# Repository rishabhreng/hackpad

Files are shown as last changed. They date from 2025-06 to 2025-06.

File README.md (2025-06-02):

# MacroPad Overview

A 6-key macropad, in an "A" shape, with a 0.91" OLED display and a rotary encoder. It also has one LED under the central key, and everything is controlled with KMK firmware.

This was my first time designing a macropad or any other  electronics with KiCad, and I really enjoyed it (esp. learning more about the wiring). Fortunately, I have some experience with CAD in Onshape, so modeling the case went smoothly.

| | |
|---|---|
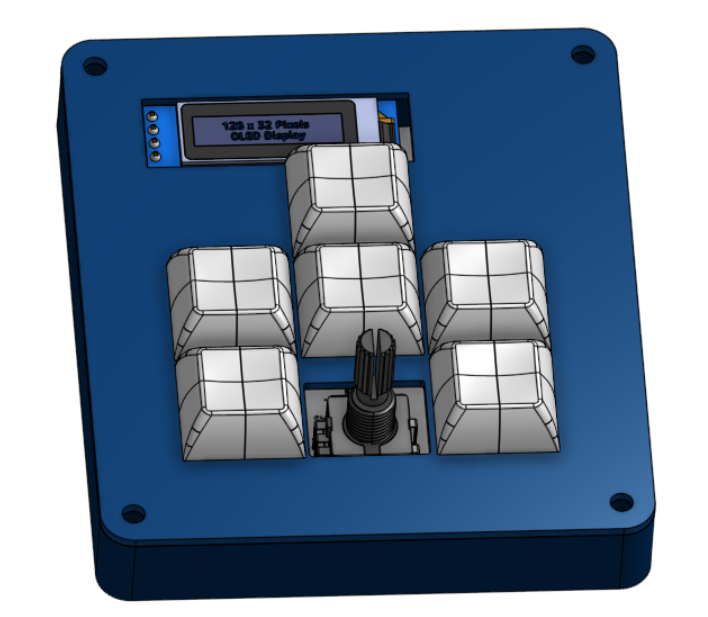
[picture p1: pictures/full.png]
3D model of my macropad
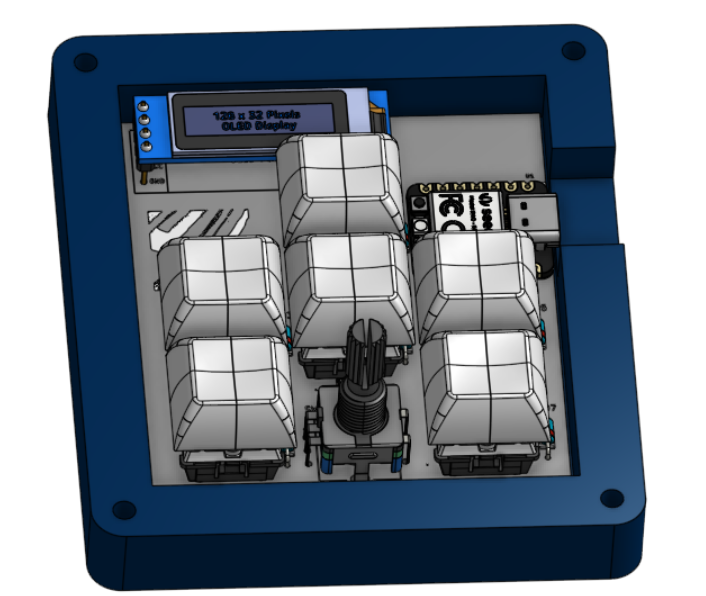
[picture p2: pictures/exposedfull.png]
full macropad, exposed PCB
|  |  |

## Pictures

| Schematic | PCB | Case |
|:-:|:-:|:-:|
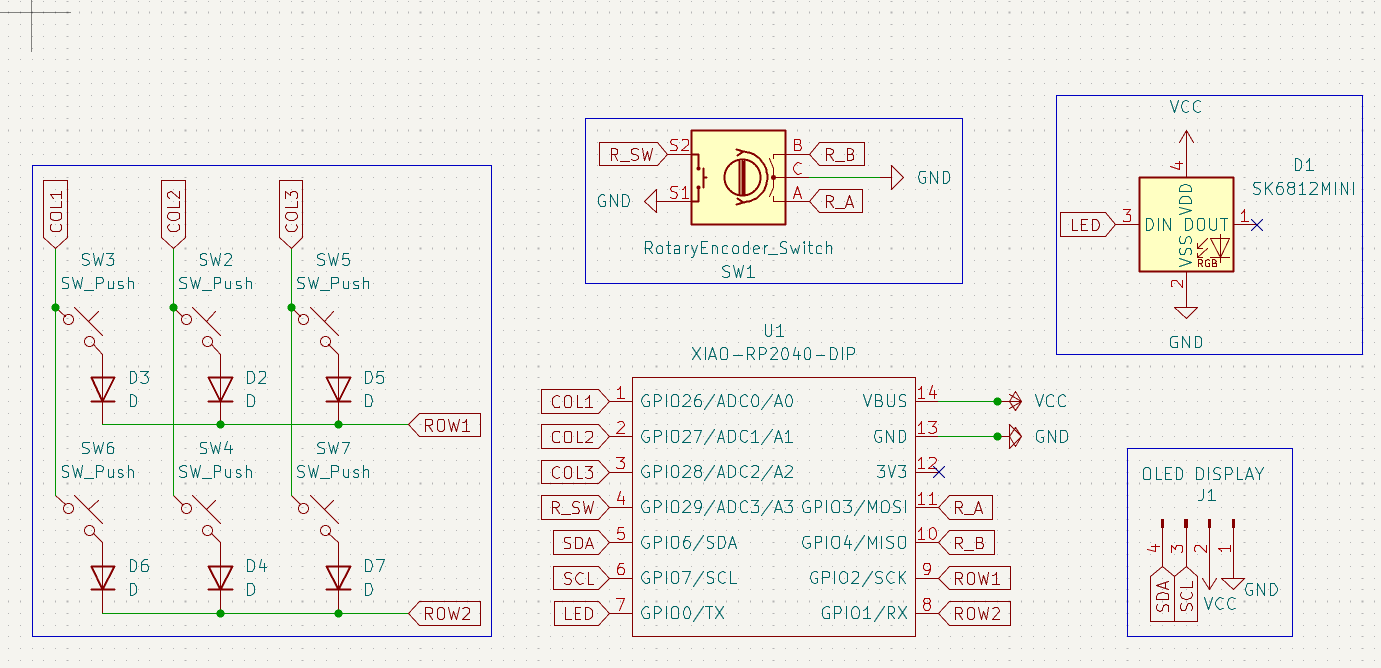
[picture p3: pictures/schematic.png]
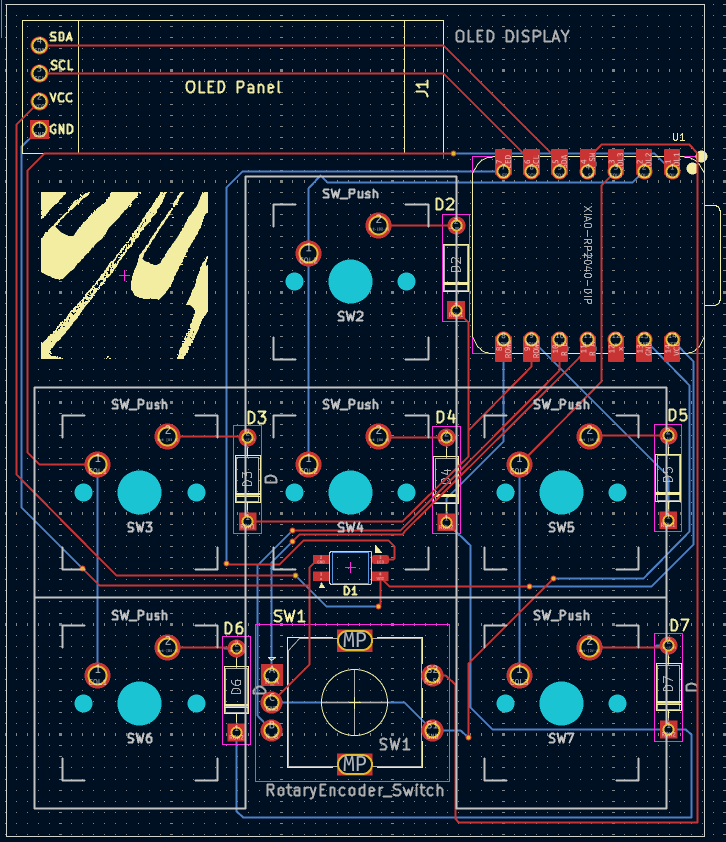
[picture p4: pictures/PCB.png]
PCB, made in KiCad
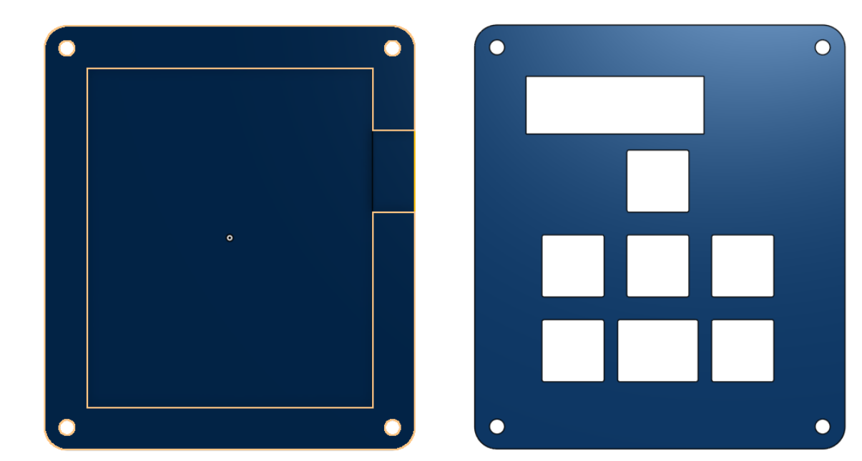
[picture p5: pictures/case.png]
|  |  |  |

**Schematic** and **PCB** designed in _KiCad_. The **CAD** model and whole assembly were designed in _Onshape_ (after trying this process in Fusion 360, I wanted to redesign in Onshape as it felt much more natural and familiar).

## Bill of Materials (BOM)

- 1x XIAO RP2040
- 6x MX-like switches
- 6x DSA keycaps
- 6x through-hole 1N4148 diodes
- 1x SK6812 MINI-E LED
- 1x 0.91" 128x32 OLED display
- 1x EC11E rotary encoder
- 1x case, made of 2 printed parts ([Top.step](production/top.step) and [Bottom.step](production/bottom.step) )
- 4x M3x16mm screws

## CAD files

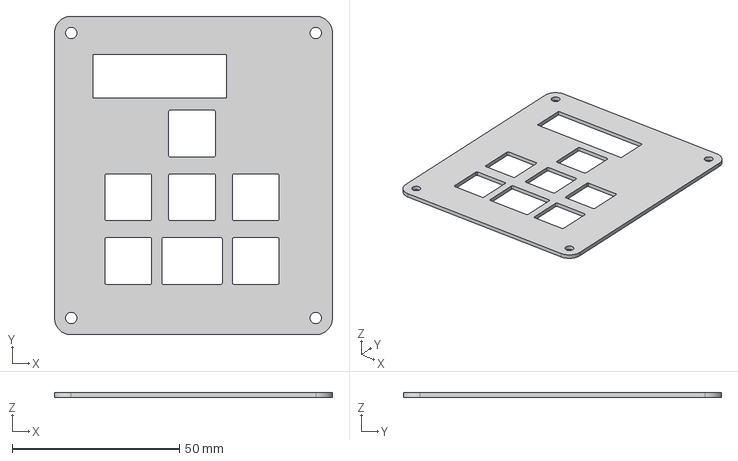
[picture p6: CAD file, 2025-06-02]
production/top.step
83.1 x 95.2 x 1.50 mm

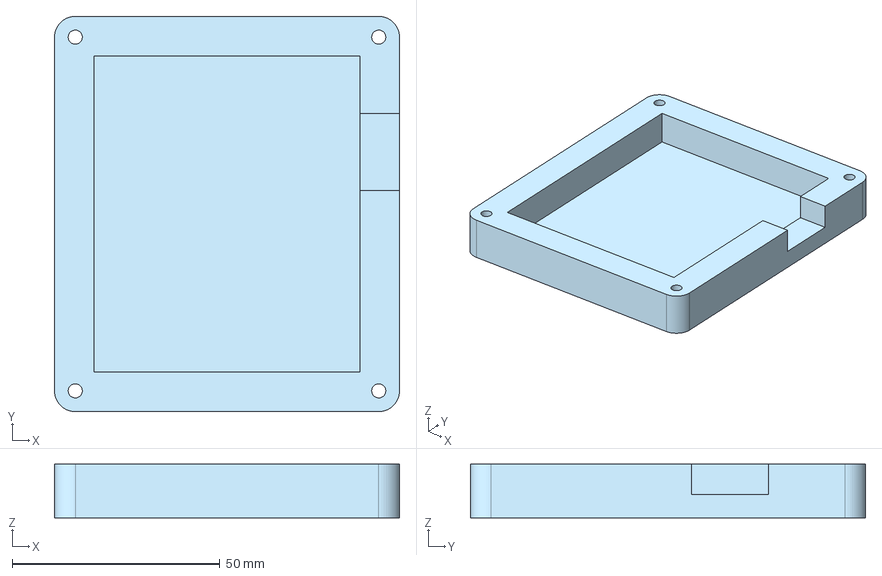
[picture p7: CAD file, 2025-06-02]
production/bottom.step
83.1 x 95.2 x 13.0 mm

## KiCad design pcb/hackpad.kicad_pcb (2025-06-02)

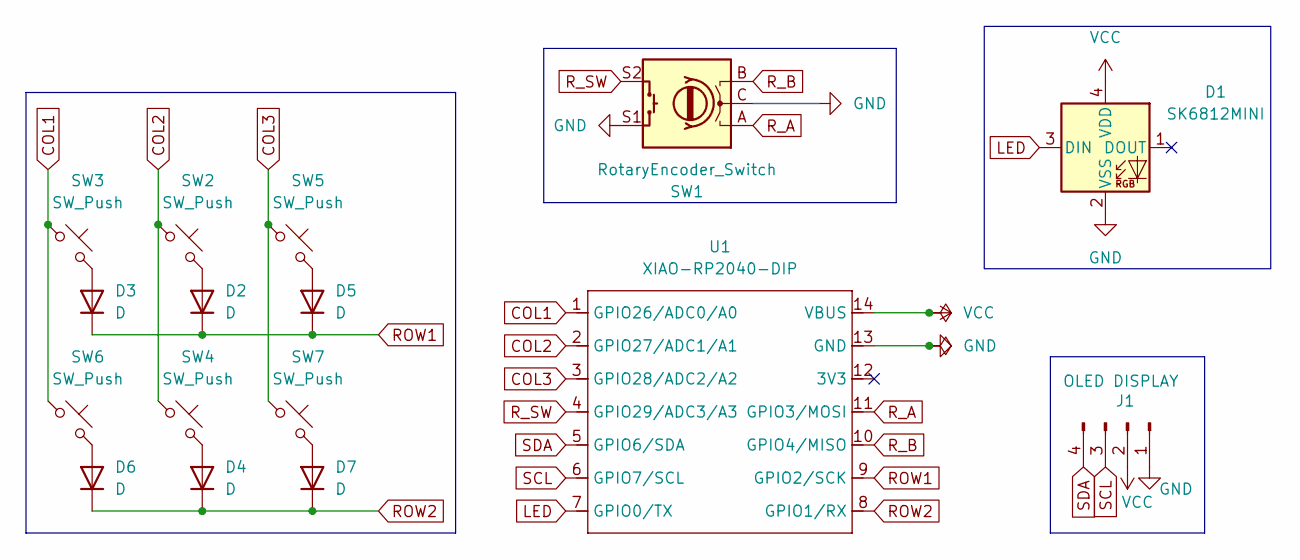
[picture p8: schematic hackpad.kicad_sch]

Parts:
D1: SK6812MINI; SK6812-MINI-E
D2, D3, D4, D5, D6, D7: D; D_DO-35_SOD27_P7.62mm_Horizontal
J1: OLED DISPLAY; SSD1306-0.91-OLED-4pin-128x32
SW1: RotaryEncoder_Switch; RotaryEncoder_Alps_EC11E-Switch_Vertical_H20mm
SW2, SW3, SW4, SW5, SW6, SW7: SW_Push; MX-Solderable-1U
U1: XIAO-RP2040-DIP

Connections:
COL1: SW3.1, SW6.1, U1.1 (GPIO26/ADC0/A0)
COL2: SW2.1, SW4.1, U1.2 (GPIO27/ADC1/A1)
COL3: SW5.1, SW7.1, U1.3 (GPIO28/ADC2/A2)
GND: D1.2 (VSS), J1.1, SW1.C, SW1.S1, U1.13 (GND)
LED: D1.3 (DIN), U1.7 (GPIO0/TX)
unnamed: D2.2 (A), SW2.2
unnamed: D3.2 (A), SW3.2
unnamed: D4.2 (A), SW4.2
unnamed: D5.2 (A), SW5.2
unnamed: D6.2 (A), SW6.2
unnamed: D7.2 (A), SW7.2
ROW1: D2.1 (K), D3.1 (K), D5.1 (K), U1.9 (GPIO2/SCK)
ROW2: D4.1 (K), D6.1 (K), D7.1 (K), U1.8 (GPIO1/RX)
R_A: SW1.A, U1.11 (GPIO3/MOSI)
R_B: SW1.B, U1.10 (GPIO4/MISO)
R_SW: SW1.S2, U1.4 (GPIO29/ADC3/A3)
SCL: J1.3, U1.6 (GPIO7/SCL)
SDA: J1.4, U1.5 (GPIO6/SDA)
VCC: D1.4 (VDD), J1.2, U1.14 (VBUS)

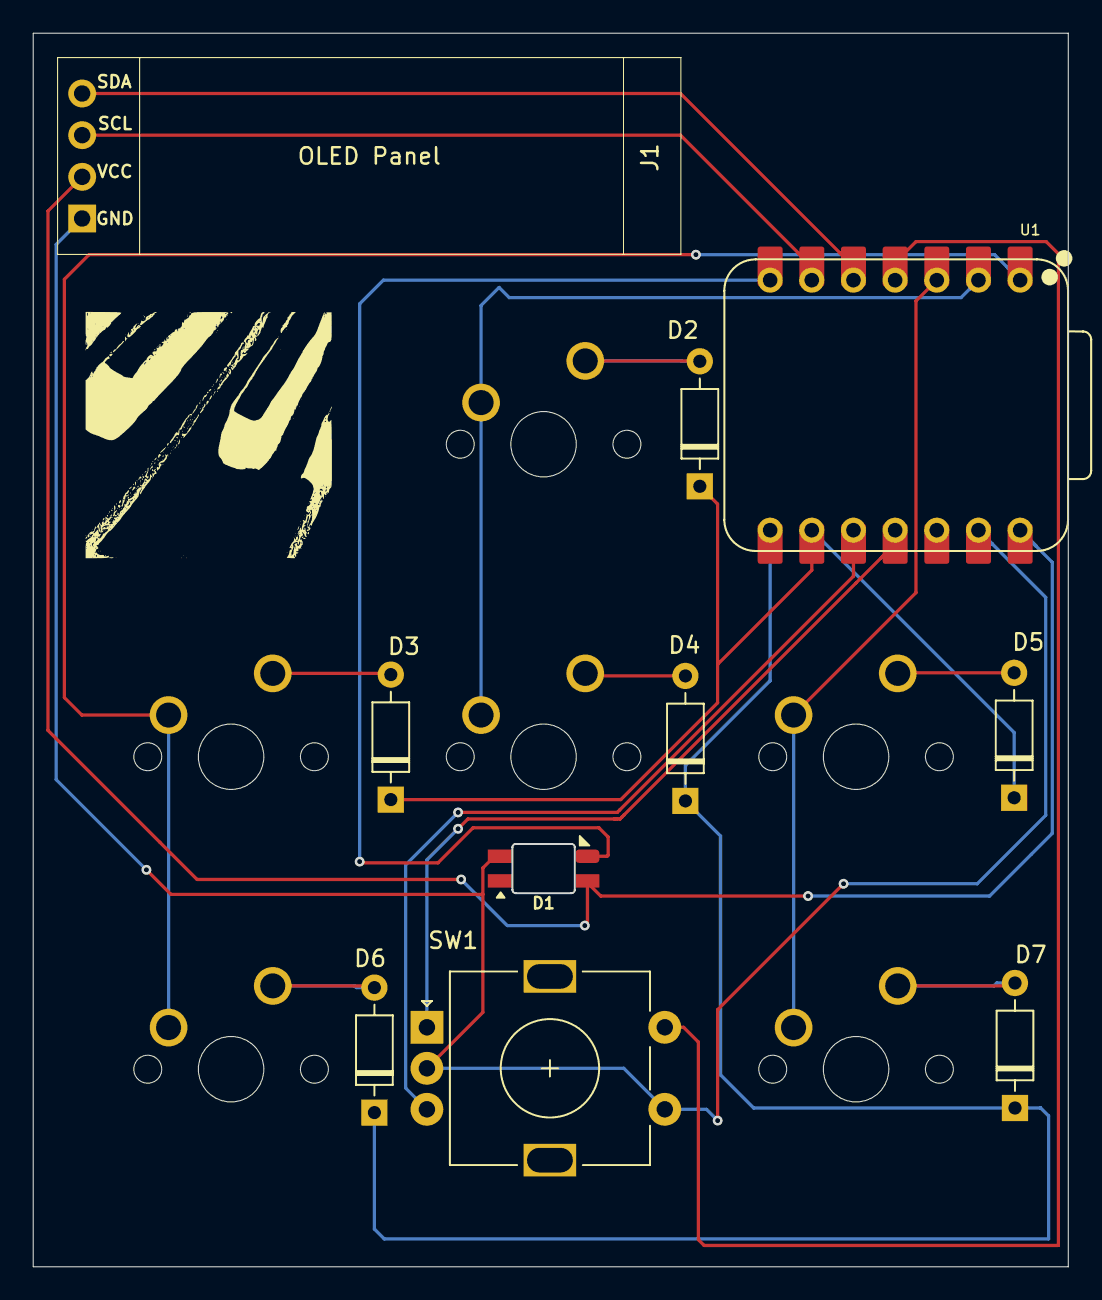
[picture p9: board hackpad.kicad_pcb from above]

Board: 2 copper layers, 63.1 x 75.2 mm, 16 parts (0 on the bottom side), 19 nets.

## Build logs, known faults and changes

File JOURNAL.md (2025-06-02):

---
title: "\"A\" 6-key macropad"
author: "rishabhreng"
description: "A 6-key macropad, in an \"A\" shape, with a 0.91\" OLED display, a rotary encoder, and an addressable LED"
created_at: "2025-05-28"
---
Total time spent: ~8.5 hours

## Day 0 – The Spark

**Time Spent:** ~0.5 hours

I’ve been relearning how to type—my speed is solid, but accuracy is poor. That got me thinking: why not build my own keyboard? Something I could customize, use in college, and evolve over time.

I rediscovered [Hack Club’s Hackpad](https://hackclub.com/hackpad/) project and remembered they offer support for exactly this kind of build. It felt like the right starting point.

---

## Day 1 – First Steps with KiCad  

**Time Spent:** ~1.5 hours  

I jumped into the beginner tutorial. Even though I didn’t fully understand what I was doing—especially with the LED wiring—it sort of made sense by the end. I customized the layout to be 4x1 instead of 2x2. Ugly? A bit. But it’s different, and that matters more right now.

Later that day, I started working in Fusion 360 for the first time. It was frustrating—I spent a good couple of days fighting with the UI trying to make a simple CAD model work.

---

## Day 2 + Day 3 – Expanding the Design  

**Time Spent:** ~2 hours  

I decided I wanted this to be more than just a tutorial clone. So I reviewed the approved parts list and committed to adding:

- A rotary encoder (for volume)
- A slightly unconventional but minimal key layout
- An OLED display (because it’s cool and versatile)

The layout took some work, especially balancing form with function, but the vision started to take shape.

---

## Day 4 – Wiring Woes  

**Time Spent:** ~1 hour  

Wiring got confusing fast. My layout meant I had to use a 3x3 matrix, which left the RP2040 with no free ports. At this point I realized: I was going to need to think like an engineer, not just a maker. I was also running into trouble keeping track of which pins went where.

---

## Day 5 – Matrix Fixes & Firmware Beginnings

**Time Spent:** ~2 hours  

More wiring hell. But something clicked: I could switch to a 3x2 matrix and wire the encoder’s push button directly to the microcontroller, freeing up a pin. I’m still not 100% sure how to process the encoder in firmware the “right” way, but I got the logic down well enough.

I also started working on the KMK firmware. At first, I had no idea how to read the encoder’s push switch—that’s what made me revisit and refine the matrix layout.

---

## Day 6 – Final Assembly in CAD

**Time Spent:** ~1.5 hours  

This was actually fun. I added in the keycaps, switches, rotary encoder, OLED display—even the LEDs—to make sure the full CAD assembly was realistic. Everything fits! It’s clean, functional, and ready to fabricate. KMK firmware done too.

---

## Done!

This project pushed me: KiCad was new, Fusion 360 was even newer, and solving firmware-level issues while managing hardware limitations was a real crash course. But now I have something custom, built for me, and flexible enough to grow with my needs. Next step-make a full keyboard like this, and using Bluetooth.

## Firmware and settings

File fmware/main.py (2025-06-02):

import board
import busio


from kmk.kmk_keyboard import KMKKeyboard
from kmk.keys import KC
from kmk.modules.macros import Macros, Press, Release, Tap
from kmk.scanners import DiodeOrientation

from kmk.modules.encoder import EncoderHandler

from kmk.extensions.RGB import RGB

from kmk.extensions.display import Display, TextEntry, ImageEntry
from kmk.extensions.display.ssd1306 import SSD1306

print(dir(board))


keyboard = KMKKeyboard()

# confgiure macros and keymap
macros = Macros()
keyboard.modules.append(macros)

keyboard.col_pins = (board.D0, board.D1, board.D2)
keyboard.row_pins = (board.D9, board.D8)
keyboard.diode_orientation = DiodeOrientation.COL2ROW


PASTE = KC.MACRO(Press(KC.LCMD), Tap(KC.V), Release(KC.LCMD))

COPY = KC.MACRO(Press(KC.LCMD), Tap(KC.C), Release(KC.LCMD))

CUT = KC.MACRO(Press(KC.LCMD), Tap(KC.X), Release(KC.LCMD))

DEL_LINE = KC.MACRO(
    Press(KC.LCMD), Press(KC.SHIFT), Tap(KC.K), Release(KC.SHIFT), Release(KC.LCMD)
)

PREV_PAGE = KC.MACRO(Press(KC.LALT), Tap(KC.LEFT), Release(KC.LALT))

NEXT_PAGE = KC.MACRO(Press(KC.LALT), Tap(KC.RIGHT), Release(KC.LALT))

keyboard.keymap = [[PREV_PAGE, PASTE, NEXT_PAGE], [COPY, DEL_LINE, CUT]]


# configure rotary encoder
encoder_handler = EncoderHandler()
keyboard.modules.append(encoder_handler)

encoder_handler.pins = (
    board.D10,
    board.D9,
    board.D3,
)
encoder_handler.map = [(KC.VOLD, KC.VOLU, KC.MUTE)]


# configure single led
rgb = RGB(pixel_pin=board.D6, num_pixels=1)
keyboard.extensions.append(rgb)

rgb.set_rgb_fill((255, 0, 0))  # Set the color to red

# configure oled 1306ssd display
driver = SSD1306(i2c=busio.I2C(board.GP_SCL, board.GP_SDA))

display = Display(
    display=driver,
    width=128,
    height=32,
    flip=False,
    brightness=1,
    dim_time=20,
    dim_target=0.2,
    off_time=60,
    powersave_dim_time=10,  # time in seconds to reduce screen brightness
    powersave_dim_target=0.1,  # set level for brightness decrease
    powersave_off_time=30,  # time in seconds to turn off screen
)

display.entries = [TextEntry(text="This works!", x=0, y=0)]

keyboard.extensions.append(display)


if __name__ == "__main__":
    keyboard.go()
